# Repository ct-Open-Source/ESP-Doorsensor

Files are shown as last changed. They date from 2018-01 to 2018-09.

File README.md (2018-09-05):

# ESP32 Türsensor / ESP32 Doorsensor

Dies ist Software für einen IoT-Türsensor auf Basis des ESP32 und des [Arduino Core for ESP32.](https://github.com/espressif/arduino-esp32) Er ist Teil des c't-Artikels ["Palim Palim" aus c't 02/2018](https://www.heise.de/ct/ausgabe/2018-2-Smarter-und-kompakter-Tuersensor-mit-WLAN-3929733.html).

This is software for an IoT doorsensor based on the ESP32 and the [Arduino Core for ESP32.](https://github.com/espressif/arduino-esp32). It is part of the c't article ["Palim Palim" in c't 02/2018](https://www.heise.de/ct/ausgabe/2018-2-Smarter-und-kompakter-Tuersensor-mit-WLAN-3929733.html).

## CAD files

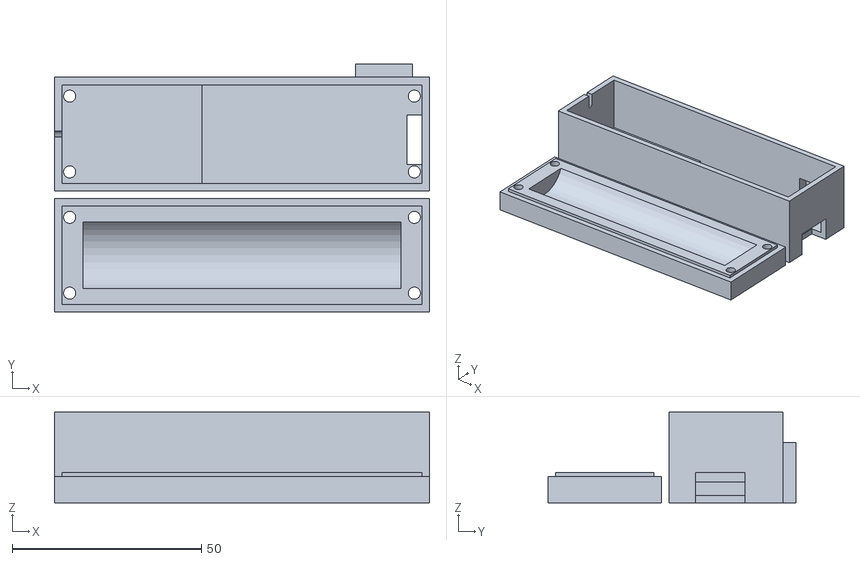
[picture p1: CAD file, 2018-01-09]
case/Case.stl
99.0 x 65.5 x 24.0

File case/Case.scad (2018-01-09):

module sensorCase_lower() {
    difference() {
        union() {
            translate([0, 0, 7/2]) cube([87+8+4, 26+4, 7], center=true);
            translate([0, 0, 8/2]) cube([87+8, 26, 8], center=true);
        }
        translate([-42, 0, 19/2+2]) rotate([0, 90, 0]) cylinder(d=19, h=84, $fn=32);
        for(i=[-1, 1]) for(j=[-1, 1]) {
            translate([i*(87/2+2), j*10, -1]) {
                cylinder(d=3.2, h=50, $fn=32);
                cylinder(d=6.5, h=3.2, $fn=6);
            }
        }
    }
}

module sensorCase_upper() {
    difference() {
        translate([0, 0, (27+2-5)/2]) cube([87+8+4, 26+4, 27+2-5], center=true);
        translate([-87/2-4, -26/2, 2+3.5]) cube([87+8, 26, 27+2-5]);
        translate([-58/2+(87+8-58)/2, -26/2, 2]) cube([58, 26, 27+2-5]);
        for(i=[-1, 1]) for(j=[-1, 1]) {
            translate([i*(87/2+2), j*10, -1]) cylinder(d=3.2, h=50, $fn=32);
        }
        translate([87/2, -8, -0.5]) cube([10, 13, 8.5]);
        hull() {
            for(i=[0, 1]) translate([-87/2-3, 0, 20+i*10]) rotate([0, -90, 0]) cylinder(d=1.6, h=10, $fn=16);
        }
    }
}

sensorCase_lower();
//color("blue") translate([0, 0, 24]) rotate([180, 0, 0]) sensorCase_upper();
translate([0, 32, 0]) sensorCase_upper();

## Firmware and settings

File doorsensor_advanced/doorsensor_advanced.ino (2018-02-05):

//Define DEBUG to get the Output from DEBUG_PRINTLN
#define DEBUG 1

//Include Basecamp in this sketch
#include <Basecamp.hpp>

//Create a new Basecamp instance called iot
Basecamp iot;

//Variables for the sensor and the battery
static const int SensorPin = 33;
static const int BatteryPin = 34;
int sensorValue = 0;
//The batteryLimit defines the point at which the battery is considered empty.
int batteryLimit = 3300;

//This is used to control if the ESP should enter sleep mode or not
bool delaySleep = false;

//Variables for the mqtt packages and topics
uint16_t statusPacketIdSub = 0;
String delaySleepTopic;
String statusTopic;
String batteryTopic;
String batteryValueTopic;

void setup() {
  //configuration of the battery and sensor pins
  pinMode(SensorPin, INPUT_PULLDOWN);
  pinMode(BatteryPin, INPUT);

  //read the status of the doorsensor as soon as possible to determine the state that triggered it
  sensorValue = digitalRead(SensorPin);

  //Initialize Basecamp
  iot.begin();

  //Configure the MQTT topics
  delaySleepTopic = "cmd/" + iot.hostname + "/delaysleep";
  statusTopic = "stat/" + iot.hostname + "/status";
  batteryTopic = "stat/" + iot.hostname + "/battery";
  batteryValueTopic = "stat/" + iot.hostname + "/batteryvalue";

  //Set up the Callbacks for the MQTT instance. Refer to the Async MQTT Client documentation
  iot.mqtt.onConnect(onMqttConnect);
  iot.mqtt.onPublish(suspendESP);
  iot.mqtt.onMessage(onMqttMessage);
}


//This function is called when the MQTT-Server is connected
void onMqttConnect(bool sessionPresent) {
  //Subscribe to the delay topic
  iot.mqtt.subscribe(delaySleepTopic.c_str(), 0);
  //Trigger the transmission of the current state.
  transmitStatus();
}


//This function transfers the state of the sensor. That includes the door status, battery status and level
void transmitStatus() {
  if (sensorValue == 0) {
    DEBUG_PRINTLN("Door open");
    //Transfer the current state of the sensor to the MQTT broker
    statusPacketIdSub = iot.mqtt.publish(statusTopic.c_str(), 1, true, "open" );
    //Configure the wakeup pin to wake if the door is closed
    esp_sleep_enable_ext0_wakeup((gpio_num_t)SensorPin, 1);
  } else {
    DEBUG_PRINTLN("Door closed");
    //Transfer the current state of the sensor to the MQTT broker
    statusPacketIdSub = iot.mqtt.publish(statusTopic.c_str(), 1, true, "closed" );
    //Configure the wakeup pin to wake if the door is closed
    esp_sleep_enable_ext0_wakeup((gpio_num_t)SensorPin, 0);
  }

  //Read the current analog battery value
  sensorValue = analogRead(BatteryPin);
  //sensorC stores the battery value as a char
  char sensorC[6];
  //convert the sensor value to a string
  sprintf(sensorC, "%04i", sensorValue);
  //Send the sensor value to the MQTT broker
  iot.mqtt.publish(batteryValueTopic.c_str(), 1, true, sensorC);
  //Check the battery level and publish the state
  if (sensorValue < batteryLimit) {
    DEBUG_PRINTLN("Battery empty");
    iot.mqtt.publish(batteryTopic.c_str(), 1, true, "empty" );
  } else {
    DEBUG_PRINTLN("Battery full");
    iot.mqtt.publish(batteryTopic.c_str(), 1, true, "full" );
  }
  DEBUG_PRINTLN("Data published");
}

//This topic is called if an MQTT message is received
void onMqttMessage(char* topic, char* payload, AsyncMqttClientMessageProperties properties, size_t len, size_t index, size_t total) {
  //Check if the payload eqals "true" and set delaySleep correspondigly
  //Since we only subscribed to one topic, we only have to compare the payload
  if (strcmp(payload, "true") == 0)  {
    delaySleep = true;
  } else  {
    delaySleep = false;
  }
}

void suspendESP(uint16_t packetId) {
  //Check if the published package is the one of the door sensor
  if (packetId == statusPacketIdSub) {
   
    if (delaySleep == true) {
      DEBUG_PRINTLN("Delaying Sleep");
      return;
    }
    DEBUG_PRINTLN("Entering deep sleep");
    //properly disconnect from the MQTT broker
    iot.mqtt.disconnect();
    //send the ESP into deep sleep
    esp_deep_sleep_start();
  }
}

void loop() {
	// Check if the ESP is up for more than 30s and shut it down to save the battery.
	if (millis() > 30000) {
    		DEBUG_PRINTLN("Entering deep sleep after 30s of idle");
		esp_deep_sleep_start();
	}
}

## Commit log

2018-01-09 Added files for 3D printed case
    [Case.scad, Case.stl]
2018-09-05 Inserted Link
